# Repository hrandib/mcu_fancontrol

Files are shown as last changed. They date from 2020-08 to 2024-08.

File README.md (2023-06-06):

# Intent
The main intent of this solution is to provide the functionality similar to [PC Fancontrol](https://github.com/hrandib/pc_fancontrol) service but in hardware. There are a lot of equipment around which have fans and are quite noisy for no particular reason. Some of them even have fan controllers but algo/control curve is usually awful. This module can solve this issue.

# Brief features
 - The module provides 2 fan control PWM channels.
 - The first channel optionally is able to control 2-3pin fans by regulating DC voltage
 - The second channel is PWM only, this is PCB only limitation (4-pin fans)
 - Channels have independent configuration but can use shared sensors
 - Up to 8 sensors are supported, 4 sensors of type LM75 and 4 sensors of type DS18B20
 - Each controller channel can use up to 4 sensors of any type
 - Controller define:
   - poll period
   - algorithm: PI, 2-Point
   - sensors binding
   - MIN and MAX limits for PWM
   - EMA filtering, etc
 - The module configuration is performed via UART using PC side Python utility, it uses YAML format for the store/upload

# The Basic Workflow
1. Connect all the sensors to the board
2. Connect the board to PC and set active channels, e.g if you won't use the first channel it can be disabled. The command expects the list of active channel numbers separated by space

```shell
python .\fanutil.py -p tty... -e 0 1
```
3. Optionally mark channels as analog, it's needed only for proper display in configuration file, functionality is not affected. The command expects the list of analog channel numbers separated by space, an empty means all channels are PWM 

```shell
python .\fanutil.py -p tty... -a 0
```

4. Read current configuration, it'll contain all recognized sensors and controllers template.</br>The sample config is available [here](./datasheet/sample.yaml)

```shell
python .\fanutil.py -p tty... -r fanconfig.yaml
```

5. Edit the configuration file according to the fields description
6. Upload it to the board

```shell
python .\fanutil.py -p tty... -w fanconfig.yaml
```

# Possible alternatives
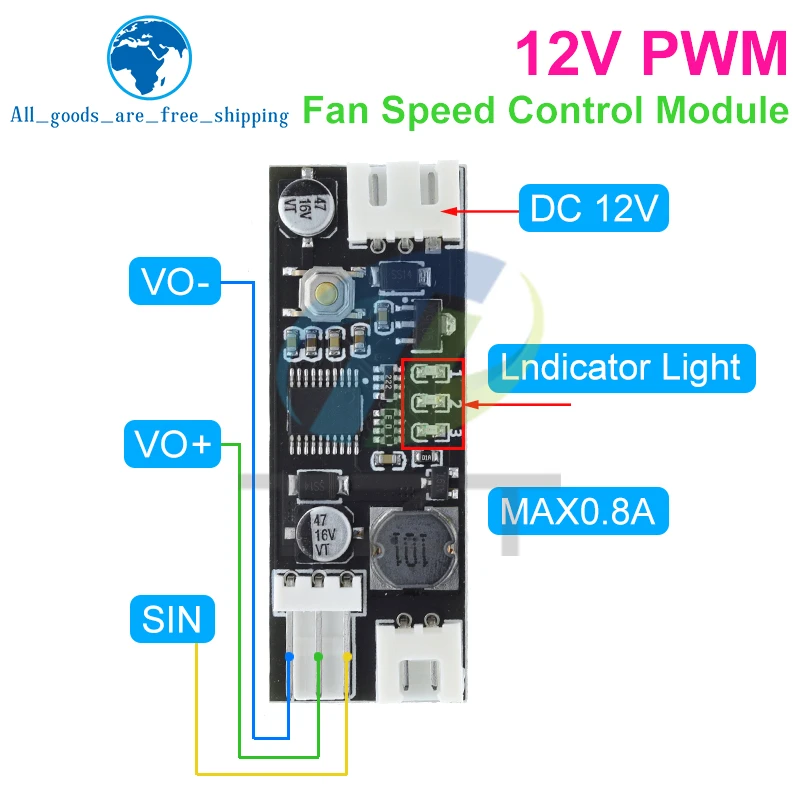
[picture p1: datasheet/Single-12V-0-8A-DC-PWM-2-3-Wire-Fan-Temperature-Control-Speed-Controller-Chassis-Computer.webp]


China market already provides various standalone fan control modules for less than 3 bucks.<br/>In many cases it's enough to solve the issue, but there are cases that can't be covered:
 - Multiple temperature measure points required
 - Multiple controller channels required with ability to share sensors
 - Other than 2-Point algo required, e.g to stabilize the temperature on the certain level

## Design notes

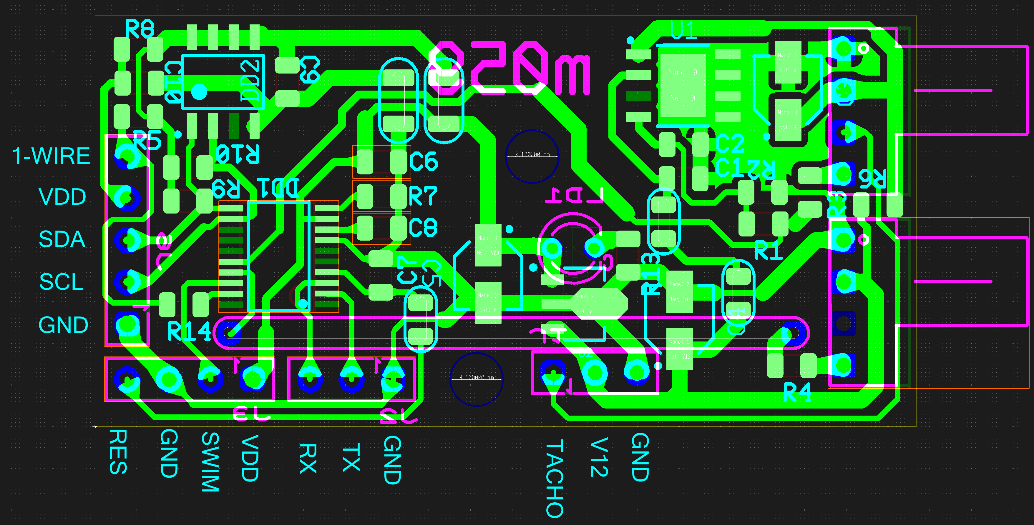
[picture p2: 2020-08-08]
sch-pcb/pcb.png

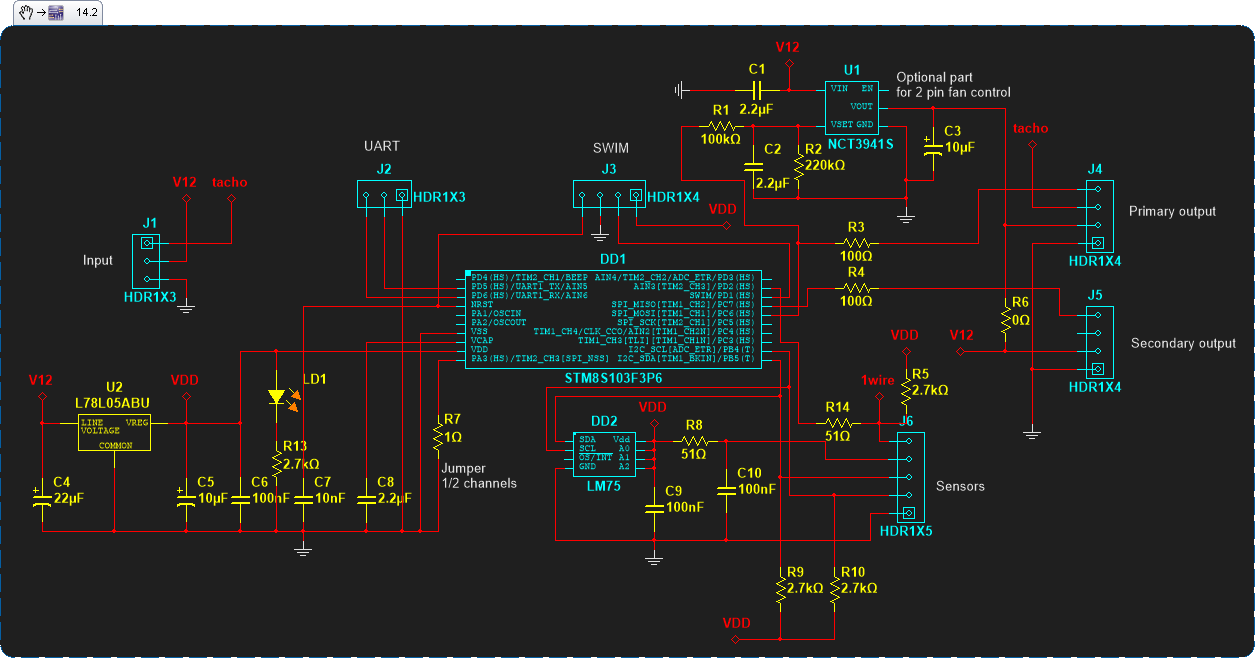
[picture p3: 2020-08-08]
sch-pcb/sch.png

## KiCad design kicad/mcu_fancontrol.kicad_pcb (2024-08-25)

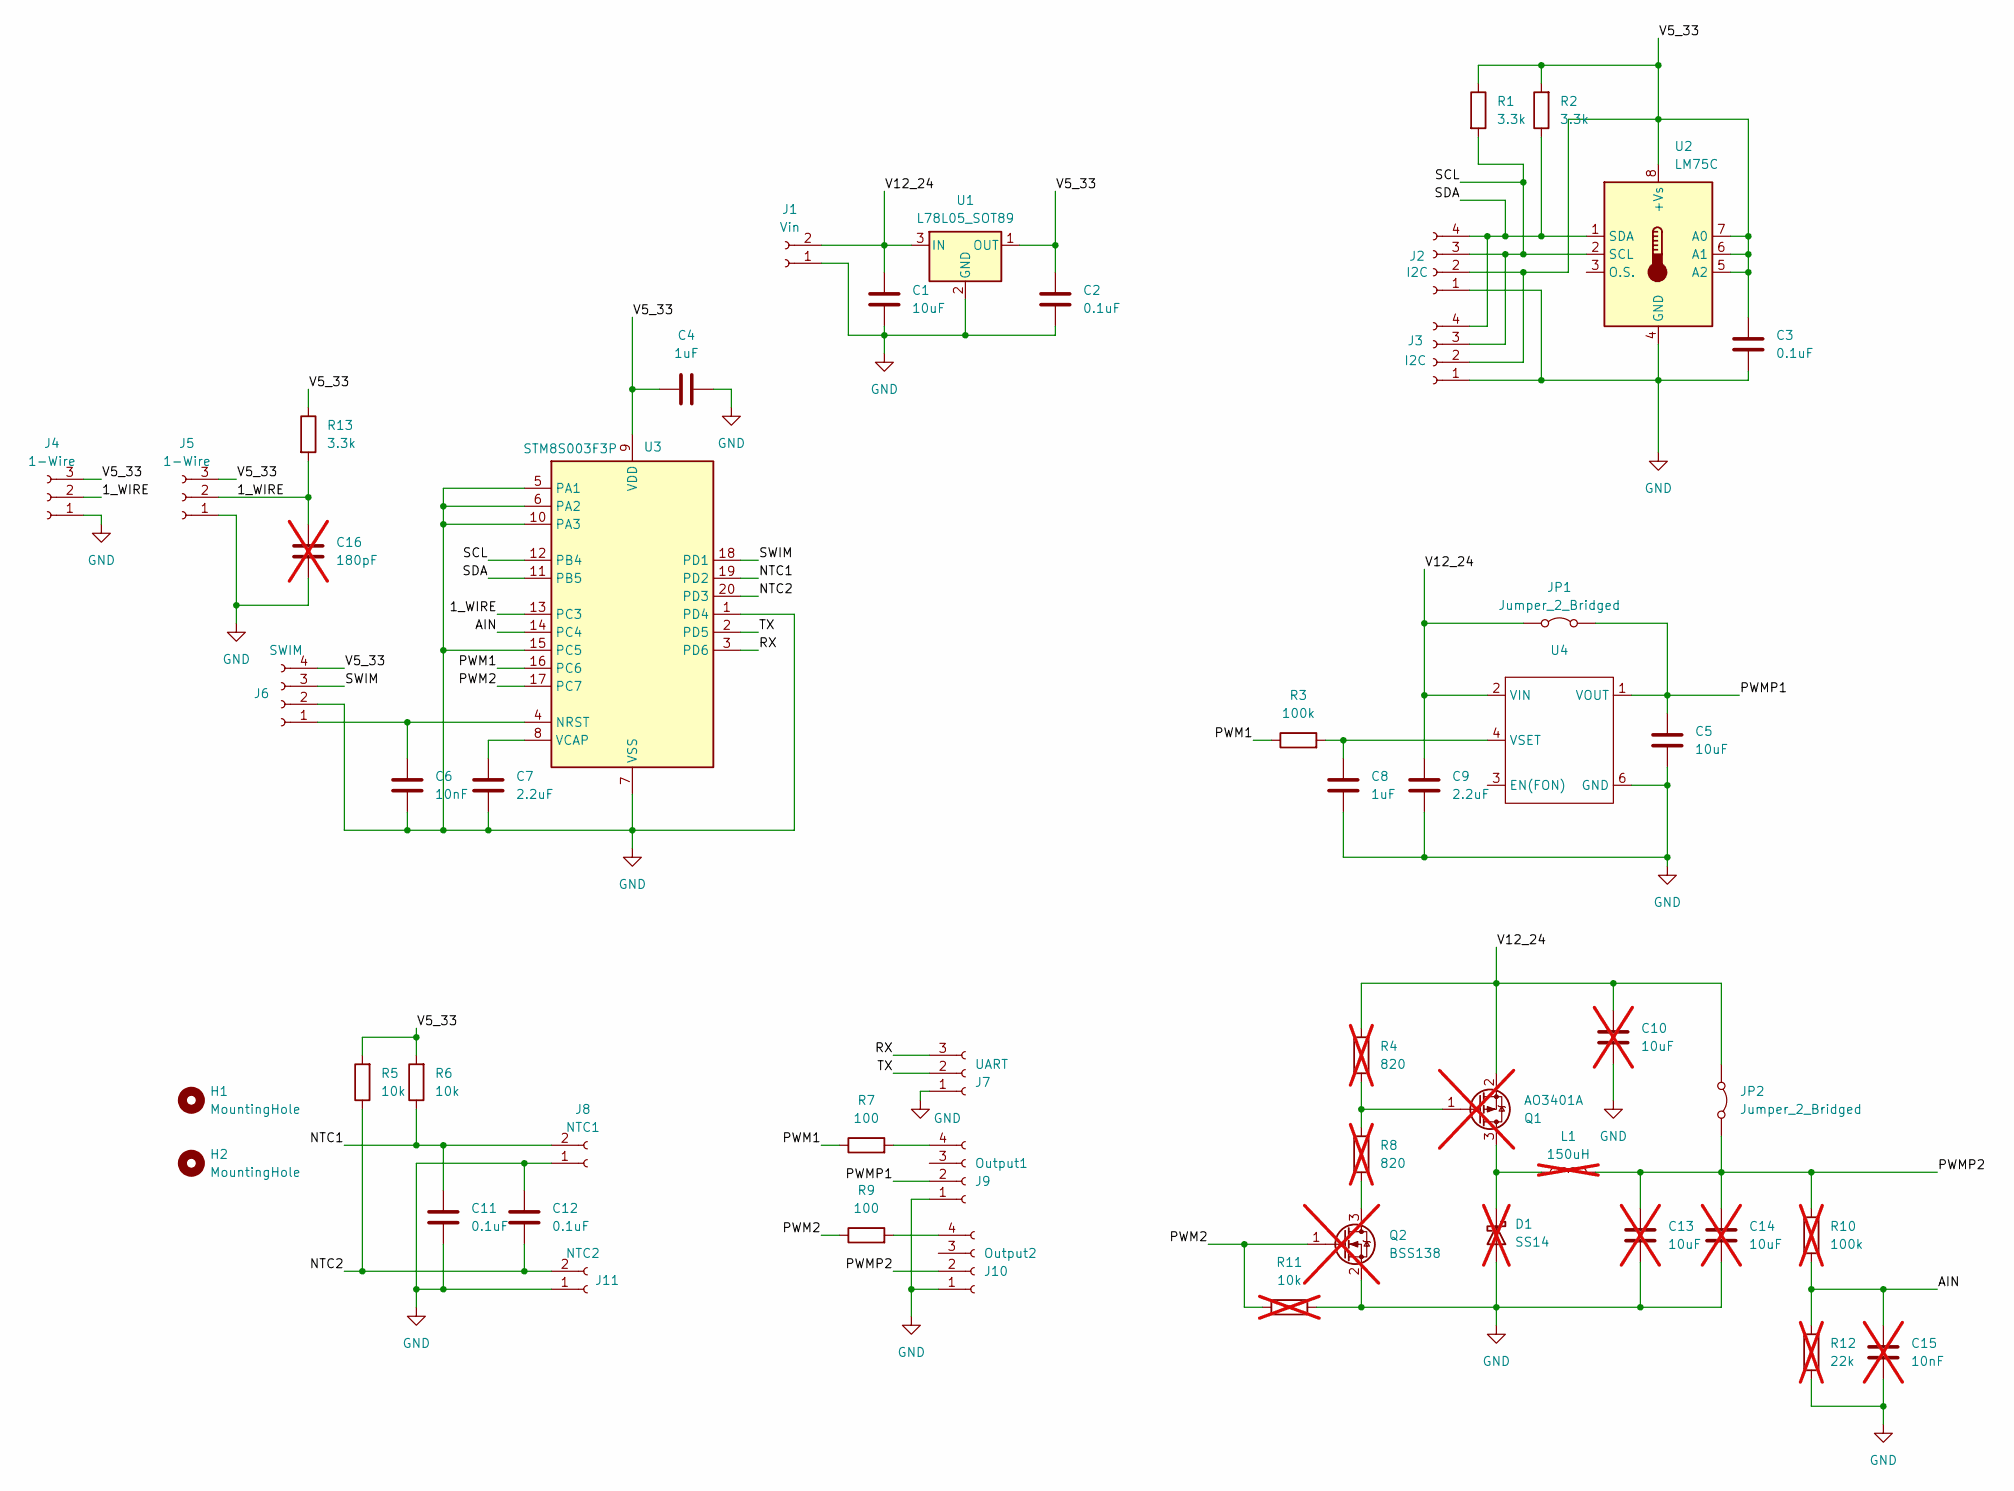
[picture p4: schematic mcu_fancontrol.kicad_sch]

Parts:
C1, C5: 10uF; C_1206_3216Metric
C2, C3, C11, C12: 0.1uF; C_0603_1608Metric
C4, C8: 1uF; C_0603_1608Metric
C6: 10nF; C_0603_1608Metric
C7, C9: 2.2uF; C_0603_1608Metric
C10, C13, C14: 10uF; C_1206_3216Metric; not fitted
C15: 10nF; C_0603_1608Metric; not fitted
C16: 180pF; C_0402_1005Metric_Pad0.74x0.62mm_HandSolder; not fitted
D1: SS14; D_SMA; not fitted
H1, H2: MountingHole; MountingHole_2.7mm_M2.5
J1: Vin; SolderWire-0.5sqmm_1x02_P4.8mm_D0.9mm_OD2.3mm
J2, J3: I2C; PinSocket_1x04_P2.54mm_Vertical
J4, J5: 1-Wire; PinSocket_1x03_P2.54mm_Vertical
J6: SWIM; PinSocket_1x04_P2.54mm_Vertical
J7: UART; PinSocket_1x03_P2.54mm_Vertical
J8: NTC1; PinHeader_1x02_P2.54mm_Vertical
J9: Output1; FanPinHeader_1x04_P2.54mm_Vertical
J10: Output2; FanPinHeader_1x04_P2.54mm_Vertical
J11: NTC2; PinHeader_1x02_P2.54mm_Vertical
JP1, JP2: Jumper_2_Bridged; SolderJumper-2_P1.3mm_Open_RoundedPad1.0x1.5mm
L1: 150uH; L_Radial_D7.0mm_P3.00mm; not fitted
Q1: AO3401A; SOT-23; not fitted
Q2: BSS138; SOT-23; not fitted
R1, R2, R13: 3.3k; R_0603_1608Metric
R3: 100k; R_0603_1608Metric
R4, R8: 820; R_1206_3216Metric; not fitted
R5, R6: 10k; R_0603_1608Metric
R7, R9: 100; R_0603_1608Metric
R10: 100k; R_0603_1608Metric; not fitted
R11: 10k; R_0603_1608Metric; not fitted
R12: 22k; R_0603_1608Metric; not fitted
U1: L78L05_SOT89; SOT-89-3
U2: LM75C; SOIC-8_3.9x4.9mm_P1.27mm
U3: STM8S003F3P; TSSOP-20_4.4x6.5mm_P0.65mm
U4: SOIC-8-1EP_3.9x4.9mm_P1.27mm_EP2.41x3.3mm_ThermalVias

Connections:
/1_WIRE: C16.1, J4.2, J5.2, R13.2, U3.13 (PC3)
/AIN: C15.1, R10.1, R12.2, U3.14 (PC4)
/NTC1: C11.1, J8.2, R6.1, U3.19 (PD2)
/NTC2: C12.2, J11.2, R5.1, U3.20 (PD3)
/PWM1: R3.1, R7.1, U3.16 (PC6)
/PWM2: Q2.1 (G), R9.1, R11.2, U3.17 (PC7)
/PWMP1: C5.1, J9.2, JP1.2 (B), U4.1 (VOUT)
/PWMP2: C13.2, C14.2, J10.2, JP2.2 (B), L1.2, R10.2
/RX: J7.3, U3.3 (PD6)
/SCL: J2.3, J3.3, R1.2, U2.2 (SCL), U3.12 (PB4)
/SDA: J2.4, J3.4, R2.1, U2.1 (SDA), U3.11 (PB5)
/SWIM: J6.3, U3.18 (PD1)
/TX: J7.2, U3.2 (PD5)
/V5_33: C2.1, C3.1, C4.1, J2.2, J3.2, J4.3, J5.3, J6.4, R1.1, R2.2, R5.2, R6.2, R13.1, U1.1 (OUT), U2.5 (A2), U2.6 (A1), U2.7 (A0), U2.8 (+Vs), U3.9 (VDD)
/V12_24: C1.1, C9.2, C10.2, J1.2, JP1.1 (A), JP2.1 (A), Q1.2 (S), R4.2, U1.3 (IN), U4.2 (VIN)
GND: C1.2, C2.2, C3.2, C4.2, C5.2, C6.2, C7.1, C8.1, C9.1, C10.1, C11.2, C12.1, C13.1, C14.1, C15.2, C16.2, D1.2 (A), J1.1, J2.1, J3.1, J4.1, J5.1, J6.2, J7.1, J8.1, J9.1, J10.1, J11.1, Q2.2 (S), R11.1, R12.1, U1.2 (GND), U2.4 (GND), U3.1 (PD4), U3.5 (PA1), U3.6 (PA2), U3.7 (VSS), U3.10 (PA3), U3.15 (PC5), U4.5 (NC), U4.6 (GND), U4.7 (NC), U4.8 (NC), U4.9 (PAD)
unnamed: D1.1 (K), L1.1, Q1.3 (D)
unnamed: C6.1, J6.1, U3.4 (NRST)
unnamed: J9.4, R7.2
unnamed: J10.4, R9.2
unnamed: Q1.1 (G), R4.1, R8.2
unnamed: Q2.3 (D), R8.1
unnamed: C7.2, U3.8 (VCAP)
unnamed: C8.2, R3.2, U4.4 (VSET)

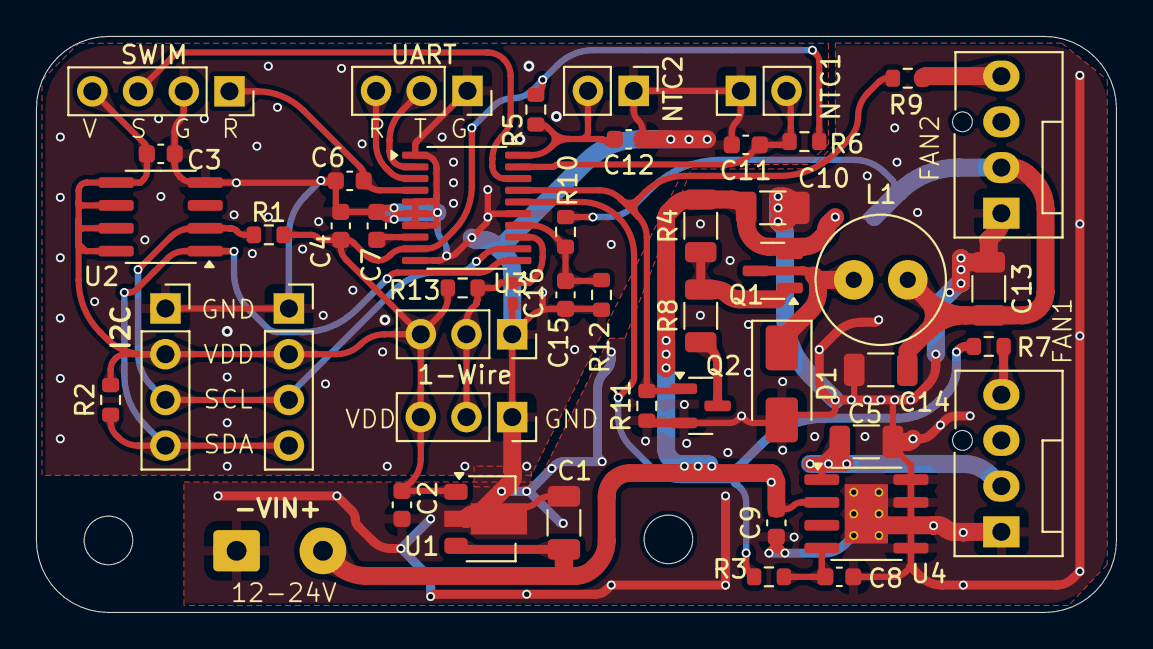
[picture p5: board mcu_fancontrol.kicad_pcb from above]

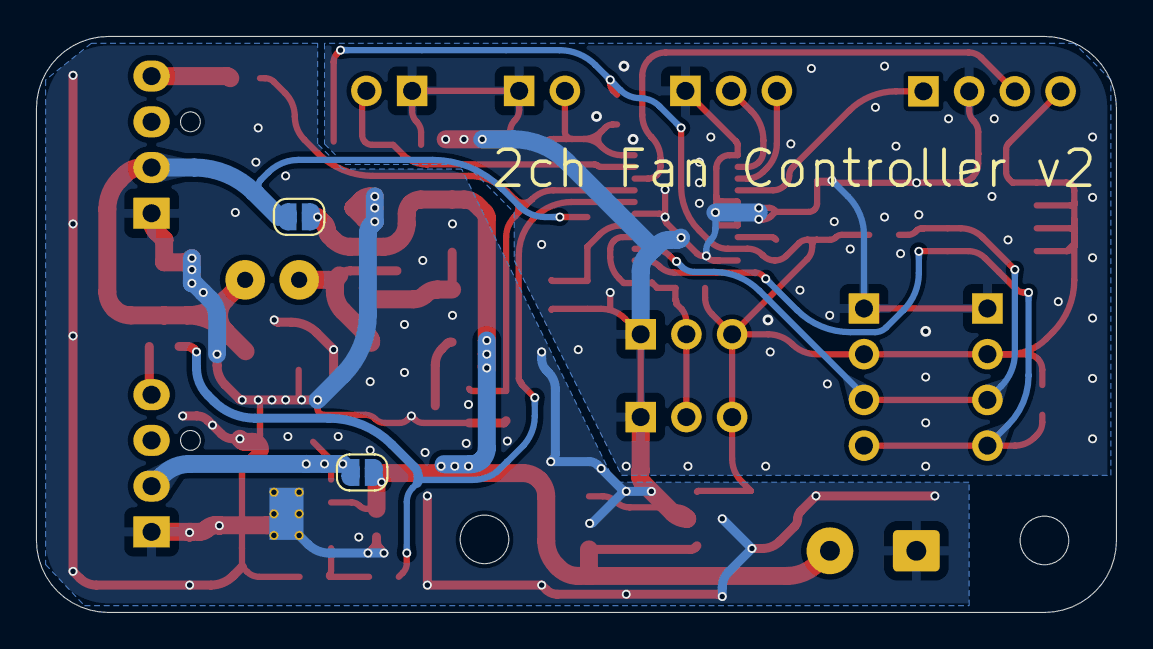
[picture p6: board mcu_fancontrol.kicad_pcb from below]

Board: 2 copper layers, 60.0 x 32.0 mm, 52 parts (2 on the bottom side), 24 nets.

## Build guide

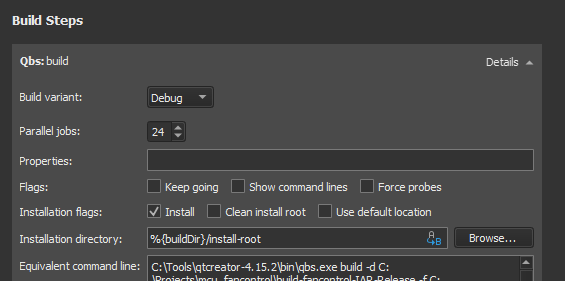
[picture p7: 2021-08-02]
datasheet/qtcreator_build_steps.png

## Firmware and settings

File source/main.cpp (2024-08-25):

/*
 * Copyright (c) 2022 Dmytro Shestakov
 *
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
 * THE SOFTWARE IS PROVIDED "AS IS", WITHOUT WARRANTY OF ANY KIND, EXPRESS OR
 * IMPLIED, INCLUDING BUT NOT LIMITED TO THE WARRANTIES OF MERCHANTABILITY,
 * FITNESS FOR A PARTICULAR PURPOSE AND NONINFRINGEMENT. IN NO EVENT SHALL THE
 * AUTHORS OR COPYRIGHT HOLDERS BE LIABLE FOR ANY CLAIM, DAMAGES OR OTHER
 * LIABILITY, WHETHER IN AN ACTION OF CONTRACT, TORT OR OTHERWISE, ARISING FROM,
 * OUT OF OR IN CONNECTION WITH THE SOFTWARE OR THE USE OR OTHER DEALINGS IN THE
 * SOFTWARE.
 */

#include "clock.h"
#include "iwdg.h"
#include "pinlist.h"
#include "scm_utils.h"
#include "sensor_handler.h"
#include "timers.h"
#include "utils.h"

static void InitPeripherals()
{
    using namespace Mcudrv;
    using namespace T4;
    // FCPU = 8MHz
    SysClock::SetHsiDivider(SysClock::Div2);
    GpioA::WriteConfig<0xFF, GpioBase::In_Pullup>();
    GpioB::WriteConfig<0xFF, GpioBase::In_Pullup>();
    GpioC::WriteConfig<0xFF, GpioBase::In_Pullup>();
    GpioD::WriteConfig<0xFF, GpioBase::In_Pullup>();
    Timer4::Init(T4::Div_128, Cfg(ARPE | CEN)); // Systick = 244Hz
    Timer4::EnableInterrupt();
}

int main()
{
    // Better to enable in option bytes
    Mcudrv::Iwdg::Enable();
    Mcudrv::Iwdg::SetPeriod(Mcudrv::Iwdg::P_1s);

    InitPeripherals();
    enableInterrupts();
    OS::run();
}

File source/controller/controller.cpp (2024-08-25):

/*
 * Copyright (c) 2022 Dmytro Shestakov
 *
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
 * THE SOFTWARE IS PROVIDED "AS IS", WITHOUT WARRANTY OF ANY KIND, EXPRESS OR
 * IMPLIED, INCLUDING BUT NOT LIMITED TO THE WARRANTIES OF MERCHANTABILITY,
 * FITNESS FOR A PARTICULAR PURPOSE AND NONINFRINGEMENT. IN NO EVENT SHALL THE
 * AUTHORS OR COPYRIGHT HOLDERS BE LIABLE FOR ANY CLAIM, DAMAGES OR OTHER
 * LIABILITY, WHETHER IN AN ACTION OF CONTRACT, TORT OR OTHERWISE, ARISING FROM,
 * OUT OF OR IN CONNECTION WITH THE SOFTWARE OR THE USE OR OTHER DEALINGS IN THE
 * SOFTWARE.
 */

#include "controller.h"
#include "device_info.h"

static void InitFanStopPin();
static int16_t GetMaxTemp(const ControlStruct& cs, SensorHandler& sh);
static uint8_t Algo2PointFunc(uint8_t channel, int16_t curTemp, const ControlStruct& cs);
static uint8_t AlgoPiFunc(uint8_t channel, int16_t curTemp, const ControlStruct& cs);
static int16_t EmaFilter(uint8_t channel, int16_t input, const ControlStruct& cs);
static void Worker(uint8_t channel, const volatile ControlStruct& cs, SensorHandler& sh);

// Sets to high logic level in fan stop condition for the second channel
typedef Mcudrv::Pd2 FanStopPin; // NTC1
typedef Mcudrv::Pd3 AuxFanPin;  // NTC2
#define AUX_FAN_HYST 10

static inline void AuxFanPinControl(uint8_t ch, int16_t curTemp, int16_t maxTemp)
{
    if(ch == 1) {
        if(curTemp >= maxTemp) {
            AuxFanPin::Set();
        }
        else if(maxTemp - curTemp >= AUX_FAN_HYST) {
            AuxFanPin::Clear();
        }
    }
}

bool isStopped[CH_MAX_NUMBER];
int16_t iVal[CH_MAX_NUMBER];
int16_t prevEma[CH_MAX_NUMBER];
uint8_t faultCounter[CH_MAX_NUMBER];

#define FAULT_MAX_COUNT 5
#define FAULT_MAX_TEMP (110 * 2)
#define FAULT_MIN_TEMP (-50 * 2)

SCM_TASK(ControlLoop, OS::pr1, 150)
{
    uint8_t pollTimeCounter[CH_MAX_NUMBER] = {};
    AuxFanPin::SetConfig<Mcudrv::GpioBase::Out_PushPull>();
    if(controlStruct[1].fanStopHysteresis) {
        InitFanStopPin();
    }
    InitPwm();
    sensorHandler.Init();
    while(true) {
        uint16_t ticks_start = get_tick_count();
        sensorMutex.lock();
        if(sensorHandler.Ds18sensorsPresent()) {
            sensorHandler.Convert();
        }
        sleep(MS2ST(SensorHandler::CONVERT_TIME_MS));
        for(uint8_t i = 0; i < CH_MAX_NUMBER; ++i) {
            if(deviceInfo.CH_ENABLE_MASK & (1U << i) && ++pollTimeCounter[i] == controlStruct[i].pollTimeSecs) {
                Worker(i, controlStruct[i], sensorHandler);
                pollTimeCounter[i] = 0;
            }
        }
        sensorMutex.unlock();
        FanStopPin::SetOrClear(isStopped[1]);
        sleep(MS2ST(1000) - (get_tick_count() - ticks_start));
    }
}

void InitFanStopPin()
{
    using namespace Mcudrv;
    FanStopPin::SetConfig<GpioBase::Out_PushPull>();
    FanStopPin::Set();
}

void Worker(uint8_t channel, const volatile ControlStruct& controlStruct, SensorHandler& sh)
{
    const ControlStruct& cs = const_cast<const ControlStruct&>(controlStruct);
    int16_t tCurrent = GetMaxTemp(cs, sh);
    // One of the sensors is damaged or absent
    if(tCurrent < FAULT_MIN_TEMP || tCurrent > FAULT_MAX_TEMP) {
        if(faultCounter[channel] != FAULT_MAX_COUNT) {
            ++faultCounter[channel];
            tCurrent = prevEma[channel];
        }
        else {
            SetPwm(channel, PWM_MAXVAL);
            return;
        }
    }
    else {
        faultCounter[channel] = 0;
    }
    tCurrent = EmaFilter(channel, tCurrent, cs);
    uint8_t pwmVal;
    if(cs.algoType == ControlStruct::ALGO_2POINT) {
        pwmVal = Algo2PointFunc(channel, tCurrent, cs);
        AuxFanPinControl(channel, tCurrent, cs.algo.p2Options.tmax * 2);
    }
    else { // ALGO_PI
        pwmVal = AlgoPiFunc(channel, tCurrent, cs);
    }
    SetPwm(channel, pwmVal);
}

int16_t GetMaxTemp(const ControlStruct& cs, SensorHandler& sh)
{
    int16_t result = INT16_MIN;
    for(uint8_t i = 0; i < cs.sensorsNumber; ++i) {
        int16_t cur = sh.GetTemp(cs.sensorIds[i]);
        if(cur > result) {
            result = cur;
        }
    }
    return result;
}

uint8_t Algo2PointFunc(uint8_t channel, int16_t curTemp, const ControlStruct& cs)
{
    uint8_t result = 0;
    const ControlStruct::Point2Algo& algo = cs.algo.p2Options;
    if(curTemp >= algo.tmax * 2) {
        result = cs.pwmMax;
    }
    else if(curTemp <= algo.tmin * 2) {
        if(cs.fanStopHysteresis && ((algo.tmin * 2) - curTemp) > (cs.fanStopHysteresis * 2)) {
            isStopped[channel] = true;
        }
        else if(!isStopped[channel]) {
            result = cs.pwmMin;
        }
    }
    else {
        uint8_t tRange = (algo.tmax - algo.tmin) * 2;
        uint16_t pwmRange = (cs.pwmMax - cs.pwmMin) << 8;
        uint16_t k = pwmRange / tRange;
        uint8_t tNorm = curTemp - (algo.tmin * 2);
        result = ((k * tNorm) >> 8) + cs.pwmMin;
        isStopped[channel] = false;
    }
    return result;
}

uint8_t AlgoPiFunc(uint8_t channel, int16_t curTemp, const ControlStruct& cs)
{
    const ControlStruct::PiAlgo& algo = cs.algo.piOptions;
    uint16_t result = 0;
    int16_t error = curTemp - (algo.t * 2);

    iVal[channel] += (algo.ki * error);
    if(iVal[channel] > (algo.max_i << 8)) {
        iVal[channel] = algo.max_i << 8;
    }
    else if(iVal[channel] < 0) {
        iVal[channel] = 0;
    }
    if(error > 0) {
        result = (((algo.kp * error) >> 5) + (iVal[channel] >> 8));
        if((result + cs.pwmMin) < cs.pwmMax) {
            result += cs.pwmMin;
        }
        else {
            result = cs.pwmMax;
        }
        isStopped[channel] = false;
    }
    else if(cs.fanStopHysteresis && error < (cs.fanStopHysteresis * 2)) {
        isStopped[channel] = true;
    }
    else if(!isStopped[channel]) {
        result = cs.pwmMin + (iVal[channel] >> 8);
    }

    return (uint8_t)result;
}

int16_t EmaFilter(uint8_t channel, int16_t input, const ControlStruct& cs)
{
    int16_t result = ((cs.kEma * input) + ((EMA_MAX - cs.kEma) * prevEma[channel]) + (EMA_MAX >> 1)) >> 7;
    prevEma[channel] = result;
    return result;
}

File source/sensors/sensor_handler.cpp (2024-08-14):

/*
 * Copyright (c) 2022 Dmytro Shestakov
 *
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
 * THE SOFTWARE IS PROVIDED "AS IS", WITHOUT WARRANTY OF ANY KIND, EXPRESS OR
 * IMPLIED, INCLUDING BUT NOT LIMITED TO THE WARRANTIES OF MERCHANTABILITY,
 * FITNESS FOR A PARTICULAR PURPOSE AND NONINFRINGEMENT. IN NO EVENT SHALL THE
 * AUTHORS OR COPYRIGHT HOLDERS BE LIABLE FOR ANY CLAIM, DAMAGES OR OTHER
 * LIABILITY, WHETHER IN AN ACTION OF CONTRACT, TORT OR OTHERWISE, ARISING FROM,
 * OUT OF OR IN CONNECTION WITH THE SOFTWARE OR THE USE OR OTHER DEALINGS IN THE
 * SOFTWARE.
 */

#include "sensor_handler.h"
#include "i2c.h"
#include "onewire.h"
#include "string_utils.h"

using namespace Mcudrv;

typedef Twis::SoftTwi<Twis::Standard, Pb4, Pb5> I2c;
typedef Twis::Lm75<I2c> Lm75;

typedef OneWire<Pc3> OneWireBus;
typedef Ds18b20<OneWireBus, SENSOR_MAX_NUMBER / 2> Ds18;

enum { COLUMN_SIZE = 6 };

static uint8_t* FormatTempData(int16_t val, uint8_t* buf)
{
    uint8_t* ptr = io::itoa8(val >> 1, buf);
    *ptr++ = '.';
    *ptr++ = val & 1 ? '5' : '0';
    *ptr = '\0';
    return ptr;
}

static uint8_t* AddSpacing(uint8_t* buf, uint8_t spaces)
{
    while(spaces--) {
        *buf++ = ' ';
    }
    return buf;
}

void SensorHandler::Init()
{
    I2c::Init();
    sensorsNumber_ = InitLm75();
    OneWireBus::Init();
    sensorsNumber_ = InitDs18(sensorsNumber_);
}

SensorHandler::SensorHandler() : sensorIds_()
{ }

void SensorHandler::PrintTemp(BaseStream& bs)
{
    uint8_t buf[8];
    for(uint8_t i = 0; i < GetSensorsNumber(); ++i) {
        int16_t rawData = GetTemp(GetId(i));
        uint8_t* pos;
        if(rawData != 0xFFFF) {
            pos = FormatTempData(rawData, buf);
        }
        else {
            pos = buf;
            *pos++ = 'N';
            *pos++ = 'A';
        }
        pos = AddSpacing(pos, COLUMN_SIZE - (pos - buf));
        bs.Write(buf, pos - buf);
    }
    bs.Write("\r\n");
}

void SensorHandler::PrintIds(BaseStream& bs)
{
    uint8_t buf[8];

    bs.Write("Sensors available: ");
    io::utoa8(sensorsNumber_, buf);
    bs.Write(buf, 1);
    bs.Write("\r\n");

    for(uint8_t i = 0; i < GetSensorsNumber(); ++i) {
        uint8_t id = GetId(i);
        uint8_t* pos = buf;
        if(id & 0x80) {
            *pos++ = 'o';
            *pos++ = 'w';
        }
        pos = io::utoa8(id & ~DS18_ID_FLAG, pos, 16);
        pos = AddSpacing(pos, COLUMN_SIZE - (pos - buf));
        bs.Write(buf, pos - buf);
    }
    bs.Write("\r\n");
}

void SensorHandler::Convert()
{
    Ds18::Convert();
}

bool SensorHandler::Ds18sensorsPresent()
{
    return (bool)Ds18::GetSensorsNumber();
}

void SensorHandler::GetValues(int16_t* buf)
{
    for(uint8_t i = 0; i < GetSensorsNumber(); ++i) {
        buf[i] = GetTemp(GetId(i));
    }
}

uint8_t SensorHandler::ConvertToDs18Id(uint8_t id)
{
    for(uint8_t i = 0; i < Ds18::GetSensorsNumber(); ++i) {
        if(id == (Ds18::GetId(i).crc | DS18_ID_FLAG)) {
            id = i;
            break;
        }
    }
    return id;
}

int16_t SensorHandler::GetTemp(uint8_t id)
{
    // Addressing to the non-existent sensor
    if(id == UINT8_MAX) {
        return INT16_MIN;
    }
    // DS18B20
    else if(id & DS18_ID_FLAG) {
        id = ConvertToDs18Id(id);
        int16_t result = Ds18::Get(id);
        return result == INT16_MIN ? INT16_MIN : result >> 3;
    }
    // LM75
    else {
        return Lm75::Read(id);
    }
}

uint8_t SensorHandler::InitLm75()
{
    uint8_t sensorPos = 0;
    for(uint8_t curSensorId = 0; curSensorId < 8; ++curSensorId) {
        if(Lm75::Detect(curSensorId)) {
            sensorIds_[sensorPos++] = curSensorId;
            if(sensorPos == SENSOR_MAX_NUMBER / 2) {
                break;
            }
        }
    }
    return sensorPos;
}

uint8_t SensorHandler::InitDs18(uint8_t indexOffset)
{
    uint8_t sensorsNumber = Ds18::Init();
    if(sensorsNumber > SENSOR_MAX_NUMBER / 2) {
        sensorsNumber = SENSOR_MAX_NUMBER / 2;
    }
    for(uint8_t i = 0; i < sensorsNumber; ++i) {
        uint8_t id = DS18_ID_FLAG | Ds18::GetId(i).crc;
        // Exclude a sensor with CRC 0bx1111111 as this ID reserved for the missing sensor
        if(id == UINT8_MAX) {
            continue;
        }
        sensorIds_[i + indexOffset] = DS18_ID_FLAG | Ds18::GetId(i).crc;
    }
    Ds18::SetResolution(Ds18::RES_9BIT);
    return sensorsNumber + indexOffset;
}

SensorHandler sensorHandler;
OS::TMutex sensorMutex;

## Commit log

2020-07-25 Initial schematic
2020-07-26 Add fan PWM specs
2020-07-26 Add pcb
2020-08-08 Add PCB connector labeling, minor design changes
2020-08-15 LM75 driver in working state
2020-08-16 Add PWM fan control demo
2021-08-16 PWM Controller in the working state
2022-02-07 Add printing of section size
2022-02-08 Add generic sensor interface
2022-02-08 Add missing license headers
    [main.cpp]
2022-02-09 SensorHandler: add LM75 support
2022-02-09 Demo: print values from all sensors
2022-02-09 Tweak temperatures printing
2022-02-09 Add sample config file
2022-02-09 Remove sensor.h iface
2022-02-10 Refactor. Drop UartStream dependency from SensorHandler
2022-02-10 Fix system timer frequency
    [main.cpp]
2022-02-10 Fix sensors number handling
    [sensor_handler.cpp]
2022-02-11 Move PWM part to the separate module
2022-02-14 Add support of the fan stop hysteresis
2022-02-14 Add Fan stop state GPIO output for CH2
2022-02-14 Rename Samples -> Utility
2022-02-14 Rename fancontrol.yaml -> sample.yaml
2022-02-14 Change to fixed packet size for Device info
    [comm_handler.cpp]
2022-02-14 Add printing sensors and control structs
2022-02-15 Fix CRC value in the default ControlStruct
    [comm_handler.cpp, control_struct.cpp]
2022-02-15 Move sample configuration to Datasheet/
2022-02-15 Update sample config
2022-02-15 Update sample remarks
2023-06-04 Add FanStop pin notes to schematic and source
2023-06-04 Change device info channel number to mask
2023-06-04 Rename root directories to the lower case
2023-06-04 Change DeviceInfo struct elements type to uint32
2023-06-04 Add channels number constant to the DeviceInfo struct
2023-06-04 Add selective printing of control structs
2023-06-05 Add more informative sensor printing
2023-06-05 Fix volatile for DeviceInfo
2023-06-05 Add UART RX flushing
2023-06-05 Implement EMA filtering feature
2023-06-05 Fix EMA scale factor
    [control_struct.cpp, fanutil.py]
2023-06-05 Add sensor ID bound check
2023-06-06 Define constant for the sensor reading delay
2023-06-06 Replace plain DS18 sensor IDs with IDs based on the sensor CRC
    This update resolves sensors configuration shifting and mix-up
    in the case of one of the sensors being damaged or missing.
    Though it introduces another issue, there is a probability of
    the sensors ID conflict, in this case, the conflicting sensor just
    will not be included in the configuration. This issue is less
    critical and doesn't have an influence on reliability unlike the
    first.
    [sensor_handler.cpp]
2023-06-06 Print sensor ID as raw hex in yaml
2023-11-27 Fix spurious unhandled GPIO interrupt
    [pwm.cpp]
2024-06-03 Add kicad updated schematics
    [mcu_fancontrol.kicad_pcb, mcu_fancontrol.kicad_sch]
2024-06-08 Add new PCB design
    [mcu_fancontrol.kicad_pcb, mcu_fancontrol.kicad_sch]
2024-06-08 pcb: Add teadrops, round tracks
    Other minor fixes
    [mcu_fancontrol.kicad_pcb, mcu_fancontrol.kicad_sch]
2024-06-08 pcb: Fix silkscreen
    [mcu_fancontrol.kicad_pcb]
2024-06-09 pcb: Fix ground plane
    [mcu_fancontrol.kicad_pcb]
2024-06-09 pcb: Minor change in the ground plane
    [mcu_fancontrol.kicad_pcb]
2024-08-14 pcb: Add iBOM
2024-08-14 src: Change 1-Wire pin to Pc3
2024-08-25 pcb: Add optional RC filter for 1-Wire
    [mcu_fancontrol.kicad_pcb, mcu_fancontrol.kicad_sch]
2024-08-25 src: Update RTOS tick rate to 244Hz
2024-08-25 src: Add 3rd relay fan control output
2024-08-25 src: Improve sensor fault detection
2024-08-25 src: Replace CRLF to LF in main.cpp
    [main.cpp]
2024-09-09 util: Fix sensor indexing in yaml
    Controllers were stored to yaml incorrectly,
    Sensor indexes mapping is fixed
    [fanutil.py]
